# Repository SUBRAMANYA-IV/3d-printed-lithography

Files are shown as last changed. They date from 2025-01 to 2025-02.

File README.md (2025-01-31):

# Introcution

As stated in the intro section, this project aims to simulate, design and prototype a 3d printed maskless photolithography system. 

Components like the optical setup, stage and overall structure should be 3d printable using basic fillament, with other off-the-shelf components like lenses, servos and other electronics easily bought from amazon. 

The most "difficult" to source parts of this project will be
- the projector: not really 'hard', but you have to make sure its an older DLP based projector with a mercury lamp, as these kinds of lamps emmit the highest amount of UV-light, which is important in curing the photoresist
- the beam-splitter and hot mirror: im still doing research into the pass-bands of the beam splitter, but this *might* require you to buy them from an actual optics company like thorlabs, which can get pretty pricy. Same with the UV-pass hot mirror: you're gonna have to gut the projector and replace its usual UV-blocking hot filter with a UV-pass hot filter so that a) the wavelength of light you want gets passed and b) the rest of the projector doesnt get fried

## Sections

This project is still in progress, and I only expect results mid way through the fall-semester of 2025. However, the general road map comes in 3 parts

##### Simulation and Sourcing

This was surprisingly one of the most time consuming parts.

I never had experience in executing this kind of project before, so I didnt know where to even start. 

One of the biggest hurdles was knowing what I could "work with". it was a feedback loop of not knowing what components you had/could use, and hence not being able to accurately simulate the optical setup. 

Best way to get over this is to just hop onto amazon and search for the components within your budget, and that (roughly) accomplish what you need. The second part is important; **dont get hung up on the details**, design around these limitations, not the other way around. 

Next biggest hurdle was simulations; I spent a solid 3-4 days just trying to find a simulation software that would fit my needs, and was open source. It'd usually go something like 
- find software
- spend 3-4 hours managing/resolving dependencies
- learn how to use the software for 2-3 hours
- realise it isnt what I wanted/needed

I dont think you can really avoid this. I ended up settling on a program called "**Aether**", which was a ray-tracing/optical simulation software written in C++ by a group at University of technology, Troyes, France. It has an intuitive GUI and is overall simple to use. The real kicker is the amount of flexibility you have in terms of defining materials and devices, all the way from refractive indicies and the IRF of bodies/surfaces to defining their behavior/response to wavelengths, and allowing you simulate data collection from sensors. 

Though I'm still learning my way around this software, so far its been incredibly useful in simulating the beam convergance with rough estimations of the optical setup. I'm still working through designing the beam splitter and filters, and this will be important to make sure UV light isn't being passed into the eye piece (which is obviously very bad), as well as any optical abberations/interference that might occur that I didnt forsee. 

one hurdle i've faced so far is the simulation of an aluminum-based beam splitter, which is giving an unexpected amount of scattering for the passed beam. 

##### Testing using an optical bread board

before 3d printing the entire project to house all the optics and the projector, it'd be best to test out the system for any optical abberations, projected image quality and other parameters/factors. 
To do this I plan on 3d printing a few optical holders and using an optical breadboard to test the whole setup, with the most important factors being
- ability of the system to focus the light onto the sample, changing the power of the objective lens as well as testing if theres enough 'leeway' with the projectors built in focusing mechanism to account for any errors
- ability of the system to project a clear, sharp image onto the sample; needs to maintain sharp "lines" while changing the microscope objective, depending on how "large" the printed image needs to be
- ability to pass/block the respective wavelengths needed; needs to be able to pass UV light through the beam splitter, which is then funneled into the objective lens, while the reflected light needs to be in the visible range to be safely viewed by the imaging sensor/eye. 
- **the most difficult part**: account for any phase shifts/optical abberations that might occur. This might require the use of diffraction gratings or other optical components to select for specific wavelengths. 

##### prototyping and assembley of the optical setup

Finally, once all the problems with the optical breadboard setup are resolved, we can model and 3d print the final setup. Given that the focusing power of the lenses I have at hand are around 200-500 mm, or 
20-50 cm, I believe the setup will be somewhat "long" to accomodate the required focusing points of each lens. 

After getting all of this to work, I'll begin working on a moving stage using the OpenFlexure project, which will allow me to either create multiple samples on a larger wafer, OR to create larger circuits by
projecting and moving the stage. The latter seems more useful but also significantly more difficult, as the stage will have to have incredible precision, along with the optical setup being able to repeatedly
project the same image, with the same precision multiple times.

### Other software

other than the simulation, I've been using FreeCad to model components like the lens holders and mount for the projector. I'll go into detail as why this is a surprisingly important aspect of the project. 

Though im still in the early stages, i'm guessing i'll also have to work with python if I want to collect and process any data, as well as C++ if I want to work with hardware in the later stages of the project when I need to control the block stage to position the wafer. 

#### Knowledge

outside of basic physics, I had no real exposure to optics until now, hence this is probably tied for the most tedious/time consuming aspect of the project. 

I had a really hard time wrapping my head around beam convergance and image formation, stemming from my confusion between point sources on an object versus the actual object being imaged. 
Though my understanding of optics is still rudimentary, resources like Physics Libre text have provided a good foundation for knowldge in the field, as well as resources from companies like Edmund Optics. 

This gave a pretty solid base for understanding compound lens setups, focal lengths, real and virtual images, and image formation, but I havent dove into ideas like optical abberations. 
I'm half hoping that, because this project utilizes short-wavelength light instead of the entire visible spectrum, abberations should be kept to a minimum.

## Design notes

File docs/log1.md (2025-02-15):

# Log 1

#### Aether Simulation

Started playing around with the Aether simulation, testing out various parameters and components. 
The simulation seems to fit in line with the calculations regarding focal lengths given standard lens sizes. 

The projector lens was given to have a throw distance between 1.5 and 12 meters, so I thought 6 meters would be a good middle ground, giving enough range to adjust the focus later on. 

The simulation was intended to test if the calculations regarding focal length using the in-contact compound lens equation, was correct. 

The light source was modelled as a collaminated polychromatic beam, with a roughly equal "distribution" of wavelengths between 100nm and 870nm.
This is likely a gross simplification of the focusing mechanism in the projector, as there are likely multiple sets of optics that move to allow for the focal point to change between 1.5 and 12 meters,
however for the purpose of the simulation it was abstracted. **all that matters is that the light focuses to a point roughly 6 meters away**

The initial projector lens seems to work as intended, focusing the incoming collaminated beams to a point on a screen 6 meters away, however the compound lens system focused the light closer than the
expected 500 millimeters from the lens, at around 400-450 mm. I can probably write this off as the distance the light travels within the lens (each of thickness 10mm) as well as the small gap between them.
Theoretically the projectors adjustable focus should be able to account for this, but its better to be safe than sorry and i'll recalculate the real focusing point using the compound lens equation accounting
for lens thickness and gap. 

This matters later on in the project, as i'll have to use a double concave lens to collaminate the light so that it can travel through the optical aperature before reaching the objective lens. 

I have to be honest I still dont fully understand how the optics inside of an objective lens work, specifically regarding FOV and if the incoming beams need to fully "fill" the aperature, and what
impact this might have on the outgoing beam. 

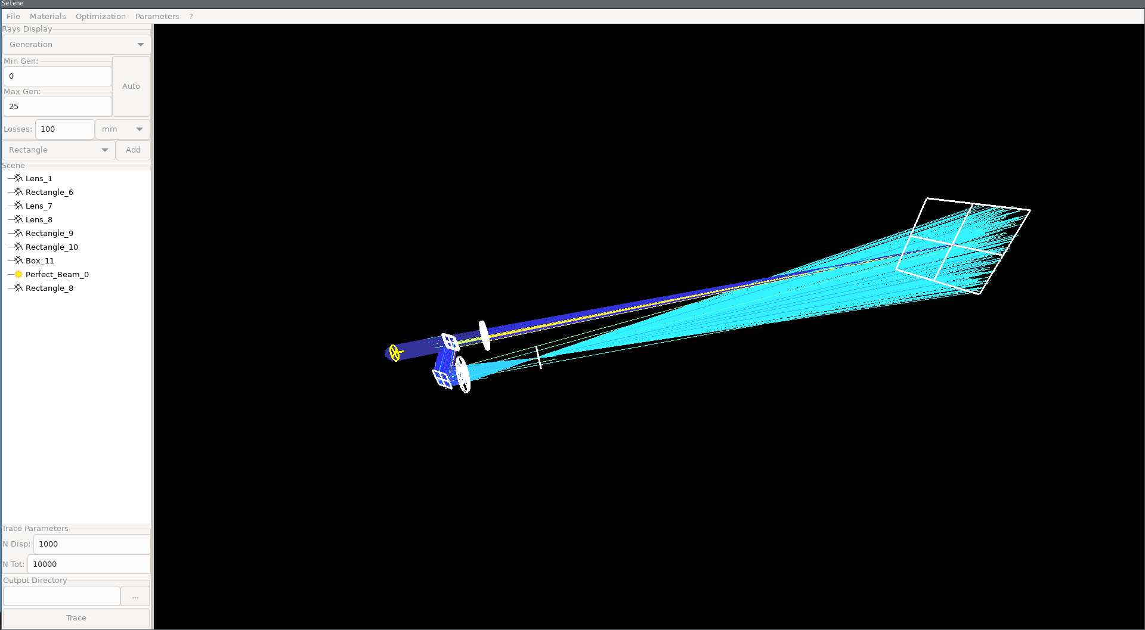
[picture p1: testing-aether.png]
optical setup


##### problems

biggest problem (which should be obvious from the image) is that the beam splitter isnt... splitting the beam. 
the idea was to simulate a beam splitter which used a thin aluminum coating, such that it passed light in the UV spectrum (100-400 nm) and reflected light in the visible spectrum and above. 
though not crucial to the project, having a dichroic beam splitter helps by not funneling UV light directly into your eye/camera sensor. This could also be avoided by using a UV filter for the
light entering the eye piece, but that would add extra components (and extra cost) to the project. 

As mentioned previously, the beam splitter should theoretically pass UV light "straight" ahead, while reflecting visible light to the second setup (used to test the focal point of a compound lens). 

I tried various setups, namely

- **single rectangle with aluminum coating on one side**
  - this setup lead to a portion of the light being reflected as expected, and entering the second optical setup.
  - the light that "passed" through the beam splitter wasn't colinear with the rest of the system, coming out at an angle. Given that snells law states $n_1sin(\theta_1)=n_2sin(\theta_2)=...n_{final}sin(\theta_{final})$, and that the initial and final materials are the same (air), then the incoming and outgoing angle should be the same, with a bit of offset due to travel in the medium. In this case it wildly shifted the outgoing angle, so im really not sure whats happening. Maybe theres some surface interaction or scattering its simulating that im not considering?
- **Two rectangles, with the first being a thin layer of aluminum and the second being glass**
  - this didnt work due to the fact that the aluminum layer was reflecting the entire portion of light. Again, not sure why. I'm still unsure of how the "inner" and "outer" surface parameters of each material work, so I might have to work with that.

I eventually settled on using a glass block in the simulation. Given the number of faces, I havent figured out the actual "orientation" or which face corresponds to what parameters. 

Reading through the docs I did however find a tool built into Aether that allows you to simulate and export your own multi-layered material, which would be the best way to simulate a dichroic beam splitter.

#### 3D modeling 

So far i've been using freeCad for my modeling, and it's been surprisingly easy to use. 90% of it seems to be the same cycle of create a sketch->pad the sketch-> attatch a sketch to a face->make features you want->repeat, with the occasional addative/subtractive primite for curved surfaces. 

The WISNED group has a optical breadboard in one of the labs, so i'm planning to use that to mount all of the optics and projectors so I can test the system in real life and adjust for any 
errors/abberations before jumping to a final setup. 

So far i've finnished the basic stand that should mount to the breadboard. This will be the base for any other components I need, including the lens holder im still working on. 

All the designs i've seen online seem to use a 3-point-of-contact, trying to minimize the contact with the lens. This makes sense for expensive lenses, but considering mine were bought off of amazon, 
i'm planning to use a flexing system that adjusts its diameter using threaded screw, with a small lip to make sure the lens is alligned vertically. 

I also have to design an adapter for the projector so that i can mount the 400mm focusing lens to it. I feel like this is going to be a bigger hurdle than the others, due to the fact the lens "moves"
when adjusting its focus, so the adapter will have to be mounted to the rim of the lens while (ideally) not rotating with it. 

i'll still have to look into tolerances and flexibility of fillament for the optical holders. 

Another huge pain has been matching the screws between metric and imperial, as well as fitting the counterbore holes into the design. The mounting holes to the base should be fine, as its intended to
screw into the optical breadboard, but the hole on the side of the design needs to be threaded so that a screw can fasten whatever optical device is inserted so it doesnt swivel. 

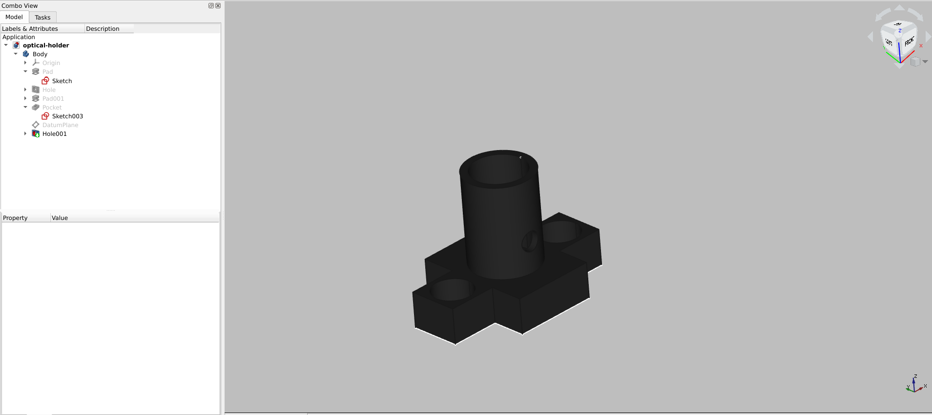
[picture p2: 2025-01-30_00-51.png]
3d-model


I also created a "blueprint"-esque diagram using Freecad's techdraw so I could more easily track the various dimensions of the optical holder when designing other components. 
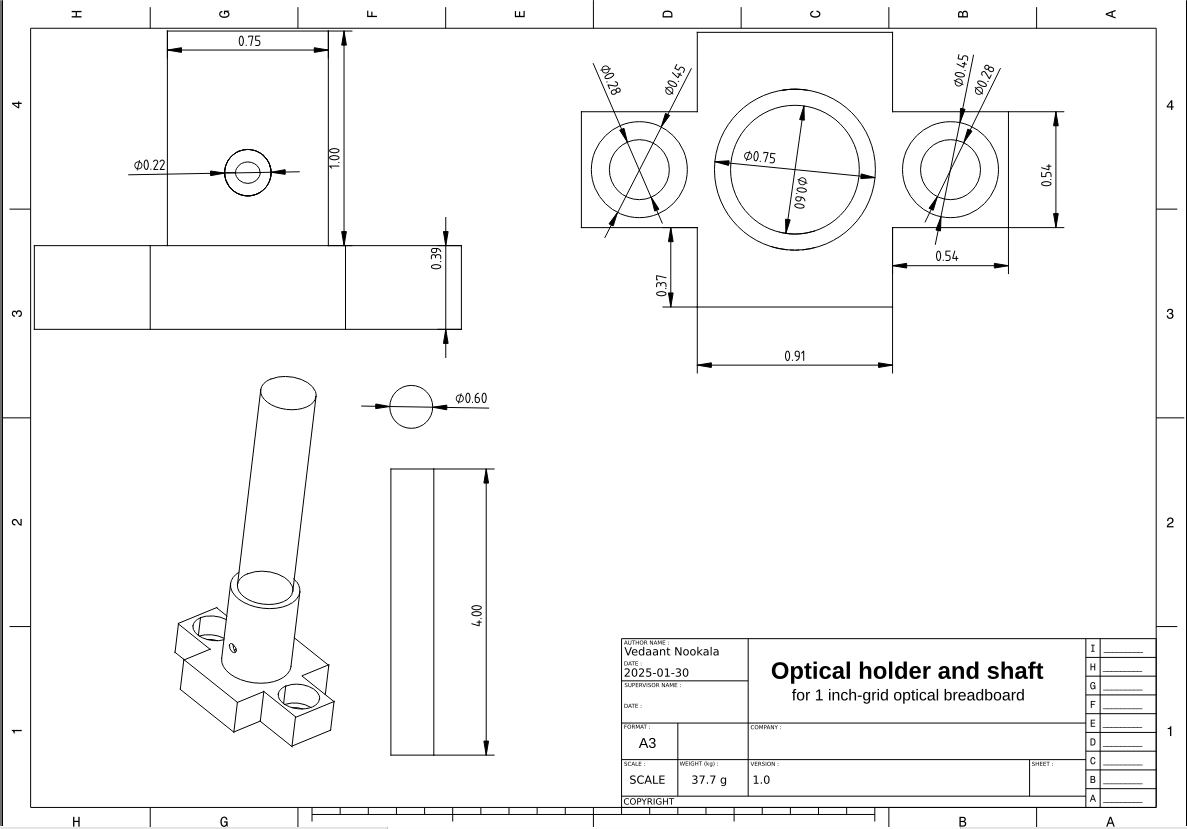
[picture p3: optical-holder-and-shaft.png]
optical-holder


This was surprisingly easy, it essentially took "pictures" of the object with its current orientation in the parts work bench, and allowed you to select any verticies or 
holes to add measurements to. 

It should be noted that the measurements are done relative to the orientation of the picture taken; ie, I tried to add a diameter measurement of a non-orthogonal view, and it gave me the error of "trying to measure the diameter of an ellipse", which is something to keep in mind.

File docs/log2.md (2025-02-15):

# Log 2

### 3d printed files

after a lot of iterations of my components, I got most of them to work pretty well. 

The biggest pain was learning what was considered 'good' practice in freecad, namely not
overusing tools like the datum plane too much, and using references to other constraints to define
geometry. The former caused a LOT of trouble when I was trying to use the base 3 inch lens
diameter holder for my 2 inch diameter holder, with a lot of the sketches "detatching" from their
respective datum plane and causing the geometries to break. 

The latter was super helpful in the same regard; it prevented my geometry from breaking often
if I changed certain dimensions. 

I initially designed the 3 inch and 2 inch lens holders to utilize threaded holes to "clamp"
down on the lens; ie, the inner diameter of the holder would be greater than that of the lens, 
and the diameter should "decrease" as I thread the screw between the 2 holes. 

This design was pretty terrible, as I'd either have to have a huge gap between the two threads,
which would require a comically long screw, or i'd have to include more complex geometries to 
account for the curveture of the outer diameter. 

Currently i've settled on a design where the inner diameter is smaller than the diameter of the lens, such that the holder "stretches" to accomodate the lens, and the elasticity of the material is utilized to "hold on" to the lens. It works well right now, but I feel like repeated insertion/removal of lenses from this setup would cause the holder to loose its elastic property, or to even snap. 

Talking about snapping, this occured pretty often with a lot of the components, namely when trying to thread the M4 screws into the holes which were meant to secure the components to each other (shaft to base, shaft to lens, etc). I'll have to add some additional material at the "junctions" of each component to prevent this, but as of right now the 3d printed components are serving me well. 

### Optical Setup

So far this has mainly been just "playing around" with the optics to get a better feel of how focal lengths, concave and convex lenses work in general. The theory and equations only go so far, so actually seeing the image being formed after placing various combinations of lenses was really fascinating. 
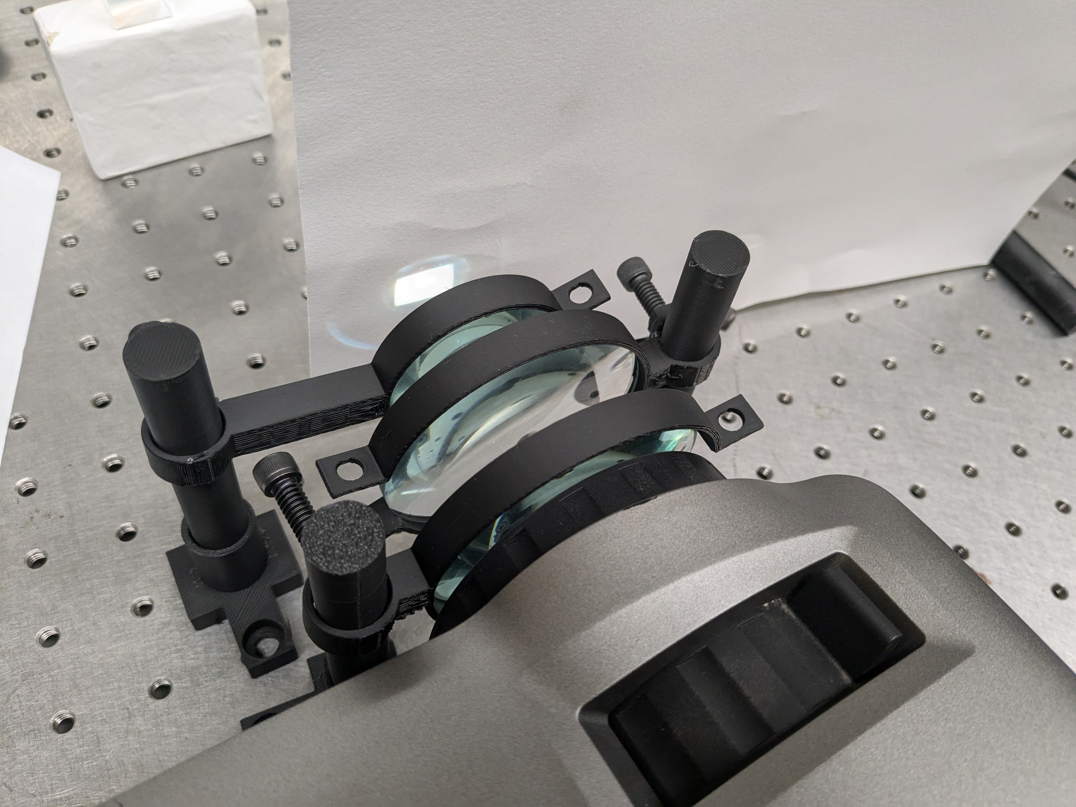
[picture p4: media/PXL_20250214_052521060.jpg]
Projector


One of the biggest hurdles I came across was how quickly the light "diverged" after exiting the lenses. I guess in my head and simulations I was assuming that the light would act as a point source, and so filling the aperature of each lens would be trivial, but I didnt really grasp how "big" the projected screen was. 

I was originally constrained to working with a 2 sets of 20,30 and 50 cm focal length lenses (both concave and convex), one of diameter 3 inches and the other of 2. I initially thought I could use 1 or 2 of the 3 inch lenses to demagnify image to an appropriate size, after which I could use the 2 inch lenses, but this wasn't the case as even at close range the lenses struggled to focus the light "fast" or "close" enough.

I ended up buying a 10 cm focal length lens of diameter 2 inches, which has worked incredibly well so far in focusing the image. I'm still getting the feel of how the lenses really interact with each other, and still somewhat struggle in effectively using the concave lenses. 
I know that they should act to "spread out" the light, as opposed to convex lenses, but 
I havent really been able to leverage that. My idea was to use them to "slow down" how fast the light converged, namely so I could pass the light through a beam splitter before refocusing it on either end of the beam splitter.
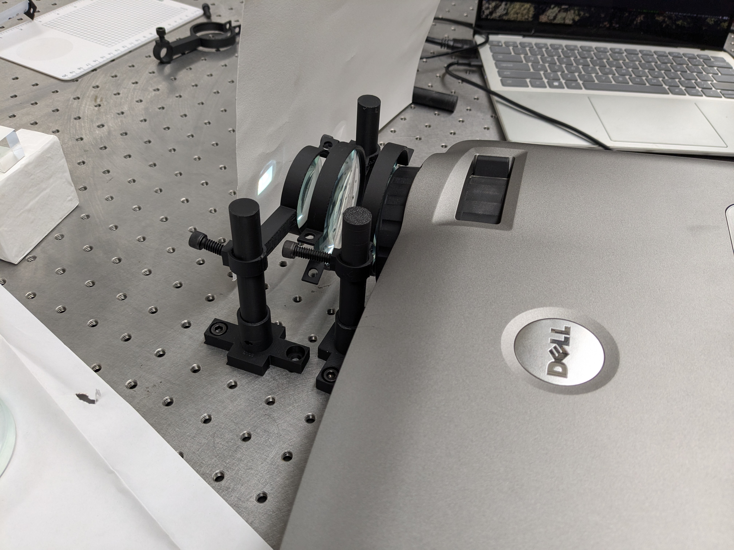
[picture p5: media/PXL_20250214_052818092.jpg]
projector2


Putting these issues aside, I was honestly amazed at how clear the projected image was. For a large part, I was able to get an image that was around 20 by 15 mm in size. 
i'm not fully sure how the projector handles resizing of resolution via screen mirroring. 
The laptop I was using had a native resolution of 1920x1200, and the projector a resolution of 1400x1050. 
I assume this means some details are lost, as the projector cant display as many pixels as the original image from the laptop can. 
The source has a pixel density of around 250 pixels per square inch, or around 10 pixels per millimeter. 
Given the projector has a resolution of 1400x1050, and that the output image was roughly 20 by 15 millimeters, this gives a pixel density of 70 pixels/mm in both x and y. 

Overall this gives a shirnkage of a factor of 9.4 horizontally and 11.3 vertically. 
This *should* mean that a 1mm feature on the original image appears as a 0.11 mm wide and 0.088 mm tall on the projected image, or around 100 micrometers. 

Overall this is pretty amazing. However, I noticed some curveture around the edges of the image, which leads me to believe spherical abberation is occuring. In my last log I somehwhat discounted any kind of abberations being an issue, assuming that because the setup was so simple I wouldn't need to worry about it. But in hind sight, using a lens with such a close focal point, while also being small in diameter (2 inches compared to the other 3 inch diameter lenses), it makes sense this would occur.
GIF

The video I took from my phone is incredibly poor quality, as evident by the high shutter speed resulting in being able to see the colorwheel spinning (which admittedly, was super cool). It also didnt caputre the sharpness of the projected image, but the fact you can distinctly make out the letters and shapes is a good sign. 

A solution to this would be to either use the same focal length lens except with a larger diameter, avoiding having the image "fill" the aperature, as I believe spherical abberation occurs the most around the edges of the lens, OR to add additional lenses behind the final focusing lens so that the incoming image has a smaller "size". 

I believe the biggest constraints I have in implementing my final optical setup is

1) the focal length is too close: I struggle to direct the beam into the beam splitter while maintaining focus, even while using a 20 cm concave lens to "slow" the convergence of light. I believe the main issue is that the image is actually forming *inside* of the beam splitter, making it impossible to project onto any surface. I might need to go with a significantly more complicated system to first focus the light into a beam that can "fit" into the dimensions of the beam splitter, after which (once exiting the beam splitter) it can be further focused to the final desired magnification. 

2) I dont have enough 3d printed components: Should be easy to solve, just print more components. However in the meantime, i've ended up just holding the lenses at various lengths from each other by hand to experiment with the demagnification and focusing of the image. Having some more standard 'sized' would also help, as the 1-inch grid pattern of the optical table is hindering me in making fine adjustments for focus. printing more optical holders should also allow me to experiment more with the idea of collaminating the light to make "working" with it easier. 

### Further Development

Now that I have the basics of the optical setup done, I think the next step should be to design a more permanent fixture to house the optics. My idea was to 3d print a kind of "sleeve" that would fit over
the projectors lens, which would then allow me to stack any combination/permutation of lenses inside of it to achieve the kind of magnification/focusing I need. In my initial setup I was somewhat limited by the 1-inch grid pattern of the optical table, which meant my lenses had to be spaced out. According to the compound lens equation, this would in effect reduce the aggregate focus of the lenses, and so this fixture should eliminate that by making sure all the lenses are in contact, minimizing the distance between them. I *hope* this results in the spherical abberation being minimized, as a result of the light being focused through the center of each lens instead of the edges (which I believe is the cause of the abberation), given that the light has less distance to disperse before reaching the lens. 

I'm also at somewhat of a crossroad in my implementation; I could either attempt to implement the setup by relying on a bunch of lenses to periodically refucs the light to avoid its dispersion/spreading out, but this would make it difficult to work with, especially in focusing it through the beam splitter. 
On the other hand, I could attempt to collaminate the light by using more of the high-power lenses, hence making it easier to work with, especially in focusing it through the beam splitter and the microscope, but this would be expensive (relatively, this is all coming out of my own pocket and the high-power lens costed around 20 dollars), and im not entirely sure it would work in capturing enough light given its 2 inch diameter. 

Furthermore, i've recently purchased a raspberry-pi 4, which would be useful in running all the software off of. Namely in controlling the projected image, but in the future also controlling the motorized stage to maintain focus more easily. 
I'll also begin work in disassembling the projector to work on the internals, namely removing the color wheel and the UV-block hot mirror. I might also play around with exposing a test-wafer to see if the projector by itself outputs a sufficient amount of UV light, so I might have to bite the bullet and order a UV-pass hot mirror from edmund optics

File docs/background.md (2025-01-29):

# background

Im Vedaant, an undergraduate student at the University of Wisconsin, Madison, with a dual degree in electrical engineering and computer science, mainly focusing on low level hardware and semiconductors. 

I'm also a part of WISNED, or the Wisconsin Nano Engineering Device Laboratory, a research group focused on materials-level device charecterization and fabrication. 
Working in WISNED gave me a decent bit of experience working on equipment and techniques in semiconductor fabrication and charecterization, namely using tools like the MJB mask alligner, spin coater, reactive ion etcher, profilometer and X-ray photoelectron spectroscopy. Really cool stuff. 

I also generally have an interest in this kind of low level hardware. This really took off after I watched a video about how insane the engineering behind the F-14 tomcats flight computer was, with the tech being used being at least a decade ahead of what was commercially available at that time. 

I didnt fully grasp how difficult this was, so I initially had lofty goals of recreating the original flight-computers on chips using modern methods and technology, mainly stuff like the 16-bit wide memory or dedicated hardware for division and mulitplication of inputs. 

After doing some more courses and getting a better grasp of computer architecture, I realized this was WAY out of my reach, but the idea of being able to fabricate custom integrated circuits with a machine that you could 

1) make cheaply; excluding equipment like the spin coater and hot-plate (both of which are either cheap to get or easy to make), the biggest hurdle to home-IC fabrication was having access to the actual lithography machine
1) make accessible; even if you could get some of the equipment off of ebay for cheap, I didnt feel it was "standardized"; you'd probably spend hours fiddling around with some decade old piece of junk to try and get it to work

in addition to this, the youtubers "Sam Zeloof" and "Breaking Taps" really gave me the final push to dive deep into this project. 

Sam's work was nothing short of insane, building a maskless lithography system in his garage and fabricating chips on-par with early intel chips. 

"Breaking Taps" to me at least kinda exemplifies what an engineer should be; specialized knowledge in one area, but still capable of quickly learning and applying ideas in all other fields. He's had projects that span at least 5 different engineering disciplines from aerospace to mechanical to electrical, and so his work inspired me to move fast and break stuff.

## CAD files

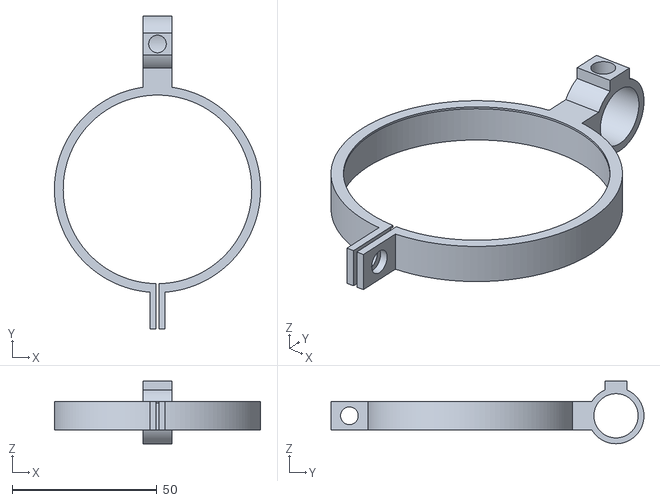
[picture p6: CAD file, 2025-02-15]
3d-files/3-inch-lens-holder-Body.stl
71.1 x 108.0 x 21.6

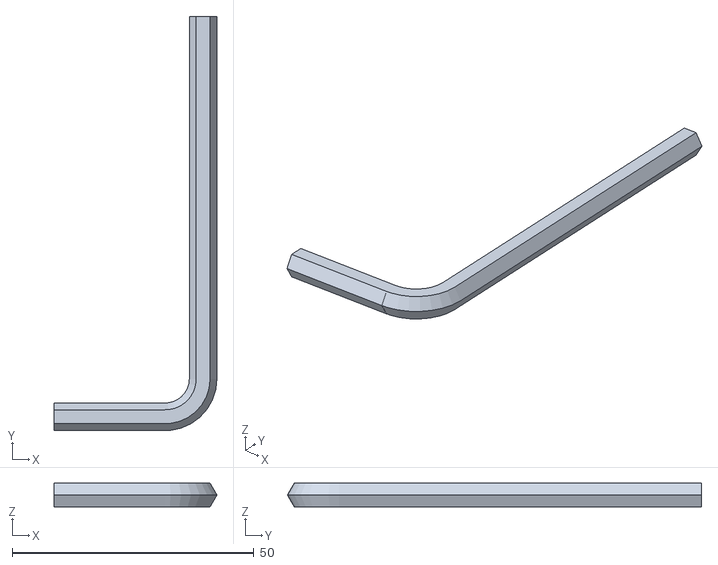
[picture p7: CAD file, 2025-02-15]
hex-set/5mm.stl
33.7 x 85.7 x 4.96

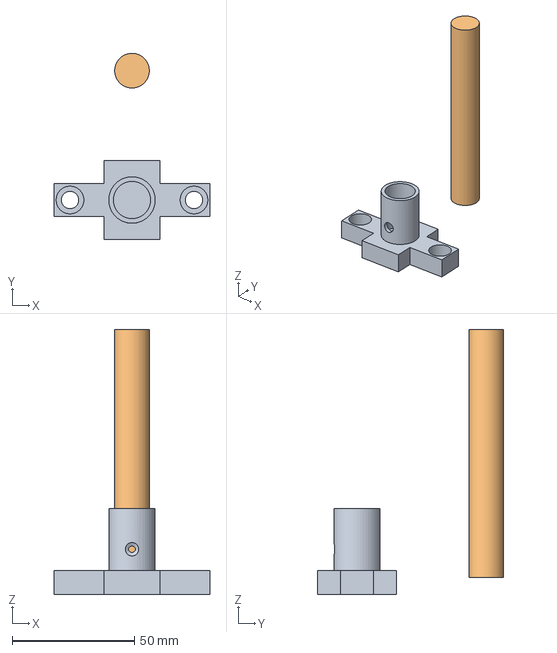
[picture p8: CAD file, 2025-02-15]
3d-files/optical-holder.FCStd
63.8 x 76.4 x 108.6 mm

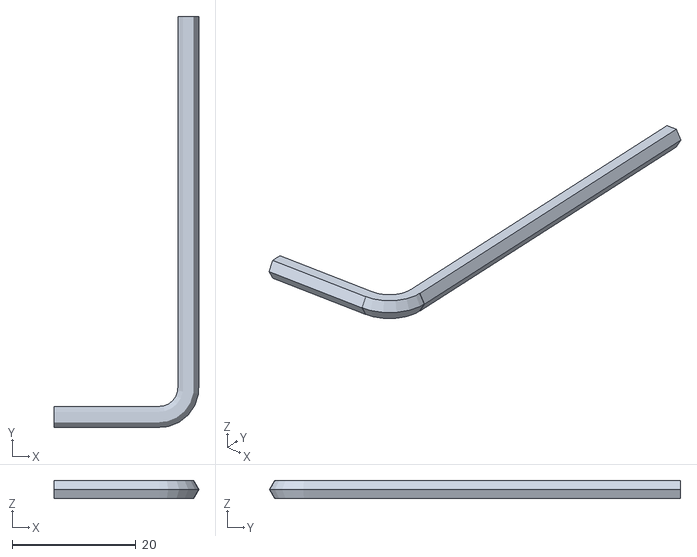
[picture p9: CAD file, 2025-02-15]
hex-set/3mm.stl
23.4 x 66.4 x 2.96

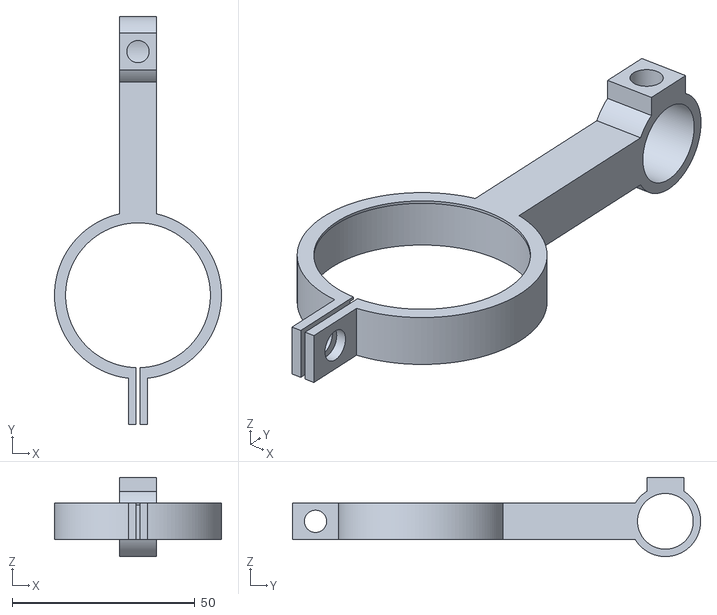
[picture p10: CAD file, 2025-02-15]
3d-files/2-inch-lens-holder-Body.stl
45.7 x 111.8 x 21.7

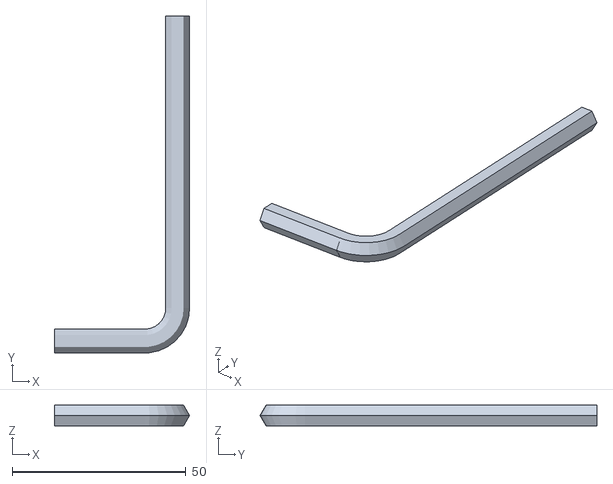
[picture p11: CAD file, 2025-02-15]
hex-set/6mm.stl
38.9 x 96.9 x 5.95

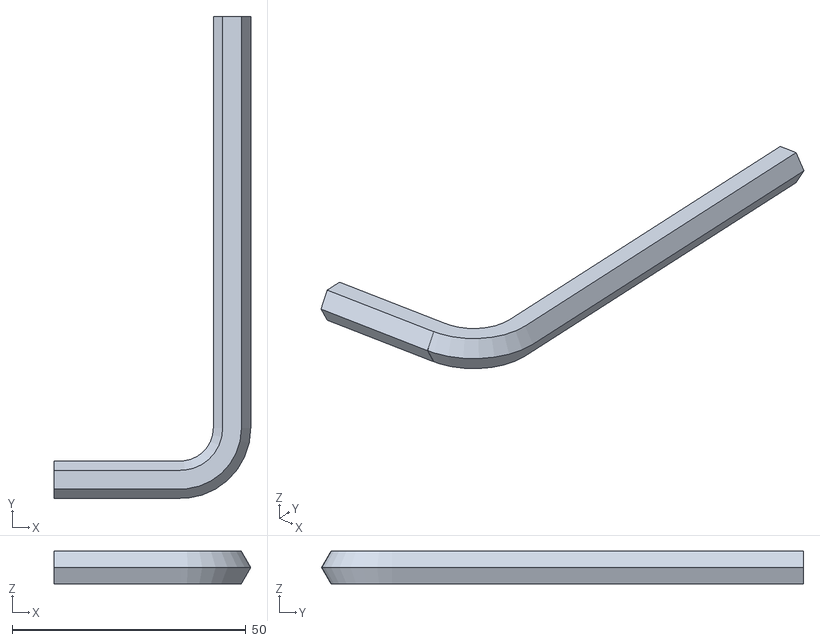
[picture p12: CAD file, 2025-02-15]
hex-set/7mm.stl
42.0 x 103.0 x 6.95

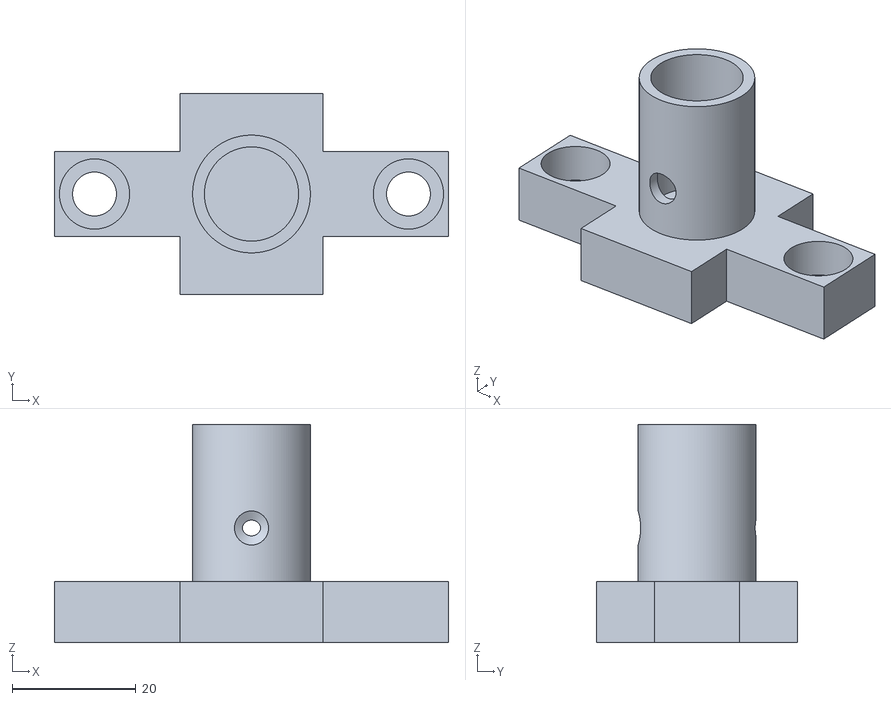
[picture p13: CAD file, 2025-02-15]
3d-files/optical-holder-Body.stl
63.8 x 32.5 x 35.3

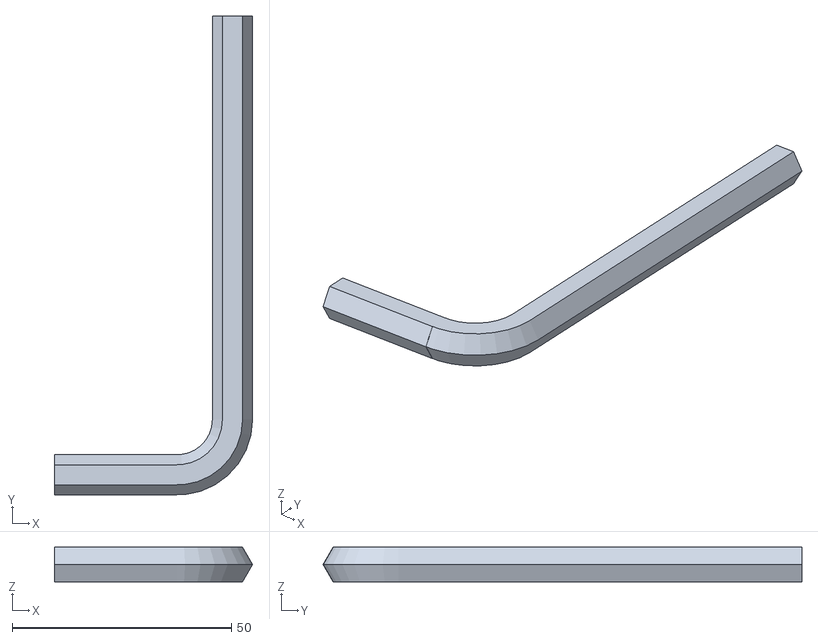
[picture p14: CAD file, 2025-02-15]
hex-set/8mm.stl
45.2 x 109.2 x 7.95

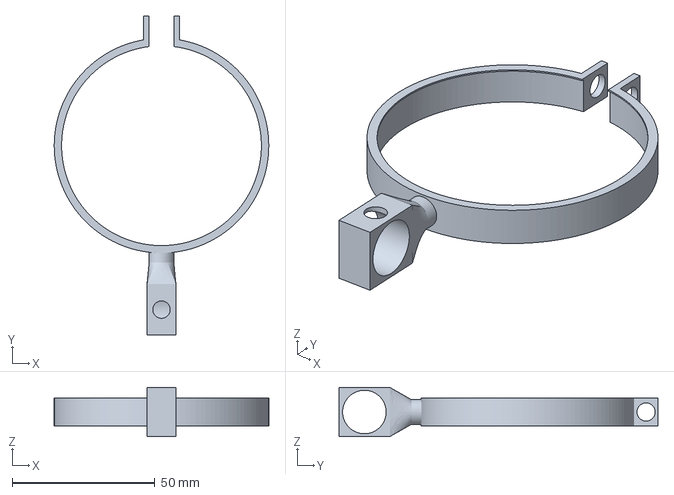
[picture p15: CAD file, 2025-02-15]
3d-files/final.FCStd
75.2 x 111.8 x 17.3 mm

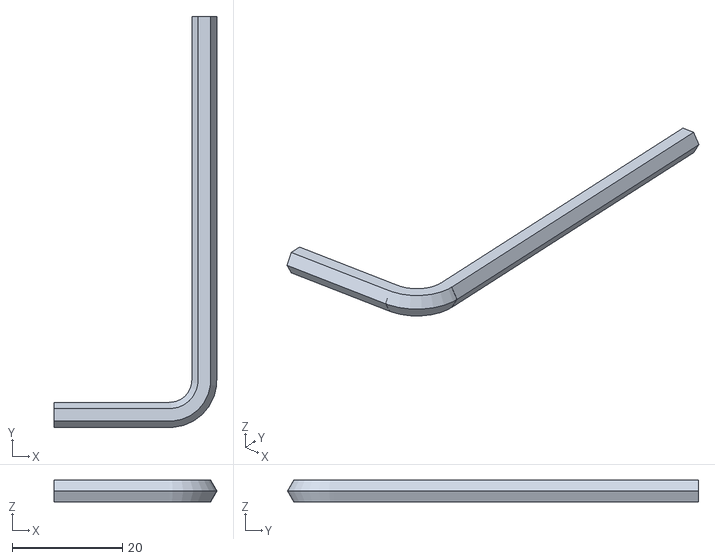
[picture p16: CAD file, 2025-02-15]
hex-set/4mm.stl
29.6 x 74.6 x 3.96

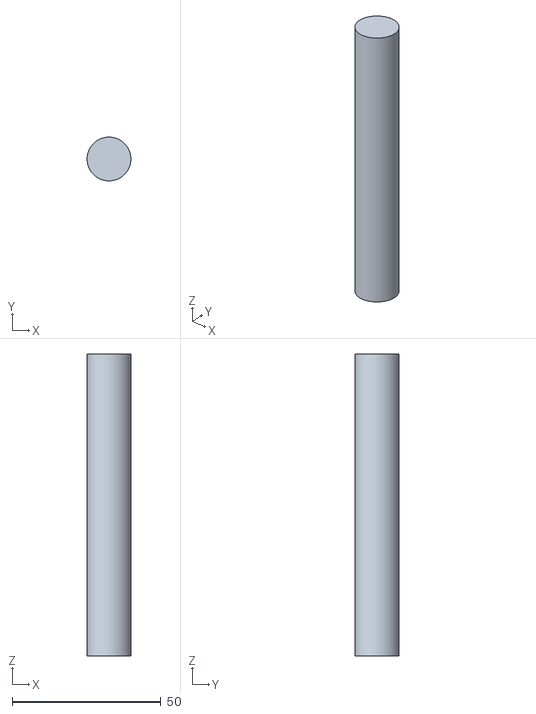
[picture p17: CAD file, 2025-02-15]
3d-files/optical-shaft-Cylinder.stl
14.7 x 14.7 x 101.6

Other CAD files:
3d-files/optical-shaft.FCStd
3d-files/2-inch-lens-final.FCStd
3d-files/3-inch-lens-holder.FCStd
3d-files/2-inch-lens-holder.FCStd
3d-files/3-inch-lens-final.FCStd
3d-files/2-inch-lens-final.stl
3d-files/2-inch-lens-holder.stl
3d-files/3-inch-lens-holder.stl

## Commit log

2025-01-30 test with image
    [optical-holder.FCStd, optical-shaft.FCStd]
2025-02-15 2025-02-15: finished log 2, accidentally removed some of the schematics/images from log 1
    [2-inch-lens-final.FCStd, 2-inch-lens-final.stl, 2-inch-lens-holder-Body.stl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]
